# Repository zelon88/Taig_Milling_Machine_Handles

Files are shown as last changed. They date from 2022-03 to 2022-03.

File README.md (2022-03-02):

# Taig_Milling_Machine_Handles
In this repo you will find a set of axis control handles that can be attached to Taig milling machines to allow for manual operation of the machine. Replaces electronic stepper motors with analog handles. Allows the  operator of the machine to control the axis' by hand. 

Along with the original source code files in .scad format you will also find renderings of each component and detailed 3D printing, manufacturing & assembly instructions.

---

# Features
* Handles are optional and modular. Will function properly with any number of handles from 0-4.
* Set screws are located to maximize holding strength and material thickness around the hub.
* Handles are hollow for minimal mass and filament consumption, but still thick enough to survive being thrown around.
* Circular design is less likely to snag on clothing or interfere with nearby work.
* High quality design with real documentation.

# Component Description
* TMMH-001 is the center disk that all other components attach to.
* TMMH-002 is the handle that the operator uses to control the orientation of the center disk, and the axis of the machine.
* TMMH-003 is a washer that slides over the pin of the handle to reduce friction during rotation of the handle.
* TMMH-004 is a washer that secures a handle assembly to the center disk.
* TMMH-005 is an assembled model of one complete handle set. This model demonstrates what the final assembly should look like.
* TMMH-006 is a model that contains every component needed to build one complete handle set arranged for optimum printability.

# Notes
* For a 3 axis Taig CNC Milling Maching you will require 3 complete sets of handles.
* This handle design does not fit on the Taig 4th axis rotary table.
* If you like this design consider following & sponsoring me on Github, or other social media @zelon88.

# Pictures
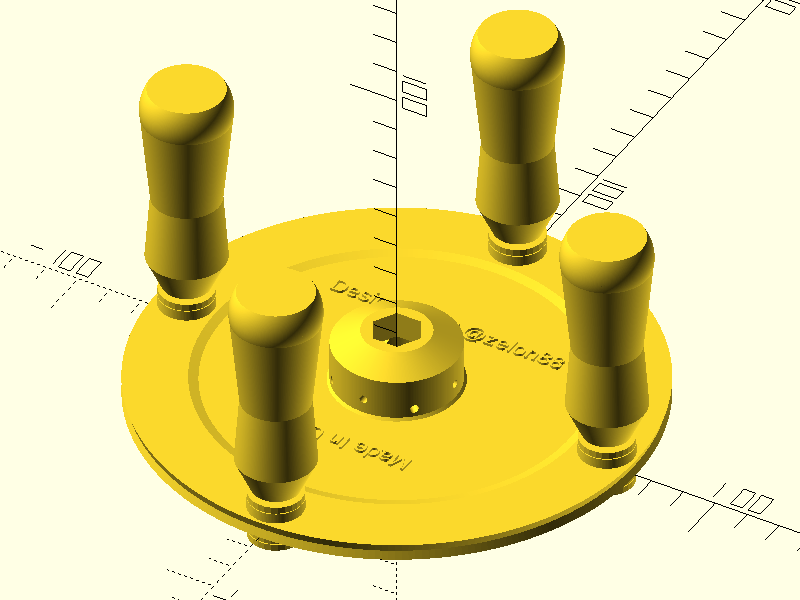
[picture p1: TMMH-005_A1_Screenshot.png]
Taig_Handles-5
	
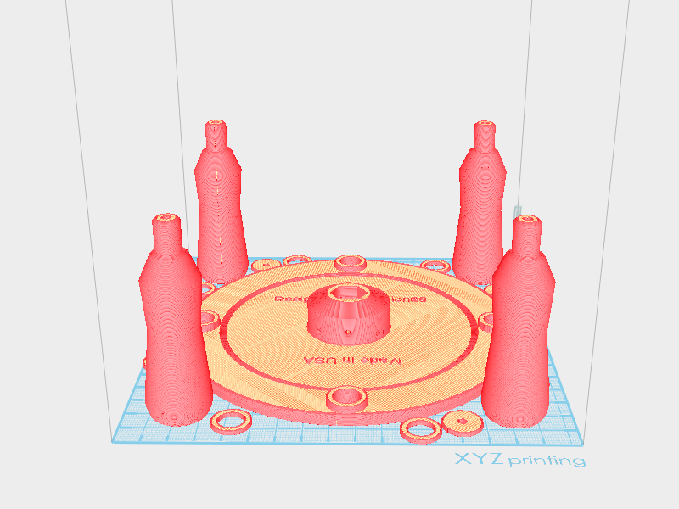
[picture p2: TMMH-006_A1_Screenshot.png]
Taig_Handles-6
	
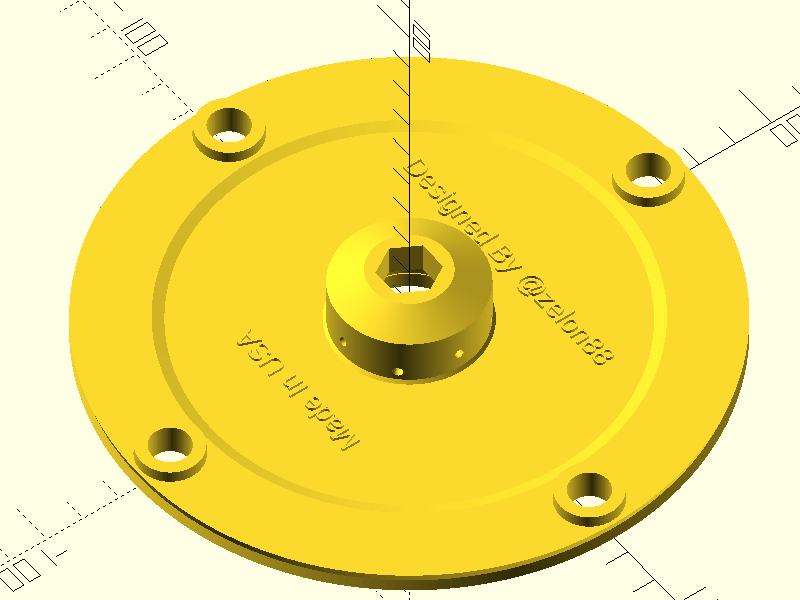
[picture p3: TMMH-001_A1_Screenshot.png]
Taig_Handles-1

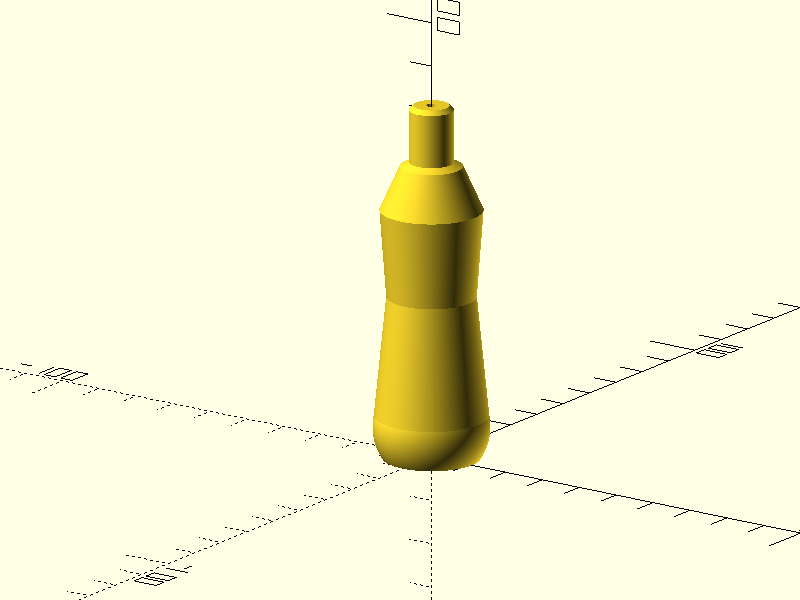
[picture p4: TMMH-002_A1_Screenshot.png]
Taig_Handles-2
	
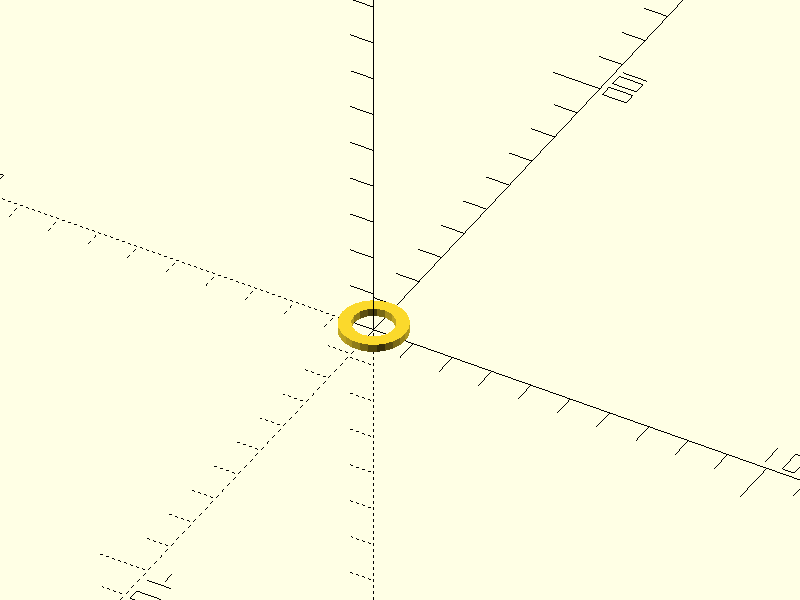
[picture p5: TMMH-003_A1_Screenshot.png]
Taig_Handles-3

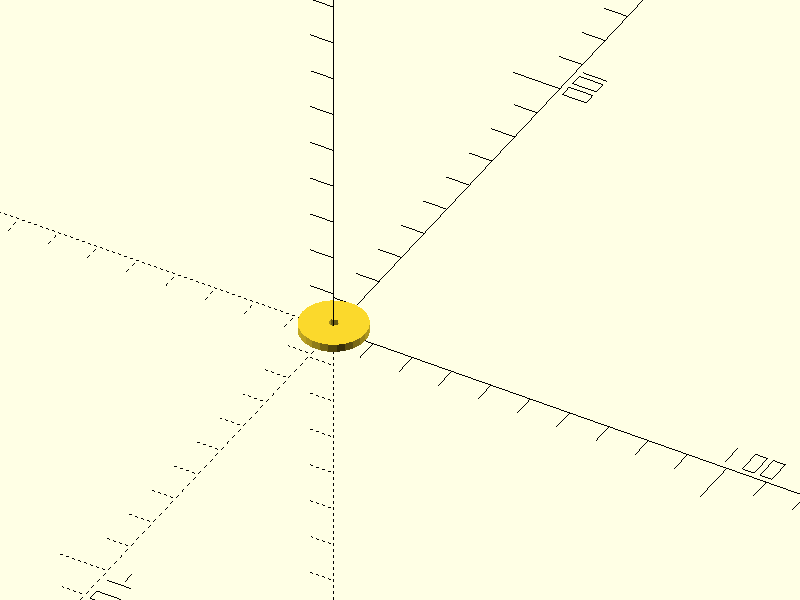
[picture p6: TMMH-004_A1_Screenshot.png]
Taig_Handles-4


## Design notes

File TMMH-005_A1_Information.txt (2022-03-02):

----------------------------------------------------------------------------------------------------
PROJECT INFORMATION

NAME:  Taig Milling Machine Handles
REVISION:  A1
START DATE:  2/28/2022
CURRENT VERSION DATE:  2/28/2022
LICENSE:  GPLv3
AUTHOR:  Justin Grimes (@zelon88)
DESCRIPTION:  A set of axis control handles that can be attached to Taig milling machines to allow for 
   manual operation of the machine. Replaces electronic stepper motors with analog handles. Allows the 
   operator of the machine to control the axis' by hand. 
----------------------------------------------------------------------------------------------------

----------------------------------------------------------------------------------------------------
PART INFORMATION

NAME:  Handle - Assembly
PART ID:  TMMH-005
REVISION:  A1
START DATE:  2/28/2022
CURRENT VERSION DATE:  2/28/2022
AUTHOR:  Justin Grimes (@zelon88)
DESCRIPTION:  The Handle Assembly contains all the components required to retrofit handles onto one 
   axis of a Taig Milling Machine. Three sets of handles are required to retrofit an entire 3 axis
   milling machine. In this assembly, four Modular Handles are shown attached to a central 
   Handle Wheel. The handle assembly function with any number of modular handles installed. 
FILE NAME: TMMH-005.scad
----------------------------------------------------------------------------------------------------

----------------------------------------------------------------------------------------------------
PRINTER CONFIGURATION

NOTE:  For bulk printing instructions; see "TMMH-006.scad".
NOTE:  For component printing instructions; see the ".scad" file for the desired component.
PRINTER TYPE:  XYZPrinting da Vinci Jr. 1.0A Pro
SLICER:  XYZPrint Version 2.0.21 
NOZZLE DIAMETER:  0.40mm
NOZZLE MATERIAL:  Copper
NOZZLE TEMPERATURE:  210c
NOZZLE FIRST LAYER TEMPERATURE:  215c
LAYER HEIGHT:  0.20mm
FIRST LAYER HEIGHT:  0.35mm
SHELL THICKNESS NORMAL:  2 Layers
SHELL THICKNESS TOP & BOTTOM SURFACE:  5 Layers
INNER SHELLS:  0mm
LIGHTWEIGHT:  No
INFILL DENSITY:  100%
INFILL TYPE:  Gyroid
DETAIL THRESHOLD:  0.001mm
AVOID CROSSING PRINTED PARTS:  No
SHELLS NORMAL SPEED:  30mm/s
SHELLS SURFACE SPEED:  30mm/s
SHELL SMALL RADIUS SPEED:  20mm/s
INFILL NORMAL SPEED:  45mm/s
INFILL TOP SURFACE SPEED:  45mm/s
SOLID INFILL SPEED:  45mm/s
BRIDGE PRINTING SPEED:  20mm/s
NON-PRINTING MOVEMENT SPEED:  50mm/s
BOTTOM LAYER SPEED:  10mm/s
RETRACT SPEED:  30mm/s
AUTO SPEED ADJUSTMENT FOR SMALL PARTS:  No
BRIM:  No
SUPPORTS:  No
RAFT:  No
RETRACT LENGTH:  4.5mm
ACTIVATE THRESHOLD (MIN TRAVEL LENGTH):  2mm
RETRACTION NOZZLE LIFT:  0mm
ADD EXTRA FILAMENT (WHEN TRAVEL < RETRACTION):  0mm
RETRACT EACH LAYER:  Yes
DISABLE RETRACTION CURRENT PERIMETER:  Yes
SHELL EXTRUSION RATIO:  100%
SHELL FILL EXTRUSION RATIO:  100%
INFILL EXTRUSION RATIO:  100%
SEAM CORNER PREFERENCES:  "Smart Hiding"
----------------------------------------------------------------------------------------------------

----------------------------------------------------------------------------------------------------
PARTS LIST

1x Handle - Wheel, TMMH-001 
4x Handle - Modular Handle, TMMH-002 
8x Handle - Modular Washer, TMMH-003 
4x Handle - Modular Endcap, TMMH-004 
8x Screws, M2.5 x 8mm 
4x Screws, M2.5 x 10mm 
12x Drops Threadlocker, Loctite Blue or Red
----------------------------------------------------------------------------------------------------

----------------------------------------------------------------------------------------------------
MANUFACTURING INSTRUCTIONS

1. Remove the desired servo motor from the Taig Milling Machine.
2. Slide TMMH-001 onto the exposed axis hub of the Taig Milling Machine with the flat side of the 
 TMMH-001 facing towards the milling machine.
3. Insert 8x M2.5 x 8mm screws into the 8x small holes located around the center hub of TMMH-001.
4. Insert TMMH-003 onto the small end of TMMH-002.
5. Insert TMMH-002 into one of the 4 large holes in TMMH-001 so that TMMH-002 is pointed away from 
 the milling machine.
6, Slowly complete one rotation of the newly installed axis before completing any more 
 installation steps. Ensure that the handle can rotate freely and is free from any obstructions.
7. Insert TMMH-003 onto the small end of TMMH-001 that remains exposed through TMMH-001.
8. Insert an M2.5 x 10mm screw into the small hole of TMMH-004 and apply one drop of 
 threadlocker to the threads.
9. Thread the M2.5 x 10mm screw with TMMH-004 attached into the small hole at the end of TMMH-002. 
10. Repeat steps 4 through 9 to add as many handles as desired.
11. Repeat steps 1 through 10 to replace as many servos as desired.
----------------------------------------------------------------------------------------------------

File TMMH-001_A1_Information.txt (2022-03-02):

----------------------------------------------------------------------------------------------------
PROJECT INFORMATION

NAME:  Taig Milling Machine Handles
REVISION:  A1
START DATE:  2/28/2022
CURRENT VERSION DATE:  2/28/2022
LICENSE:  GPLv3
AUTHOR:  Justin Grimes (@zelon88)
DESCRIPTION:  A set of axis control handles that can be attached to Taig milling machines to allow for 
   manual operation of the machine. Replaces electronic stepper motors with analog handles. Allows the 
   operator of the machine to control the axis' by hand. 
----------------------------------------------------------------------------------------------------

----------------------------------------------------------------------------------------------------
PART INFORMATION

NAME:  Handle - Wheel
PART ID:  TMMH-001
REVISION:  A1
START DATE:  2/28/2022
CURRENT VERSION DATE:  2/28/2022
AUTHOR:  Justin Grimes (@zelon88)
DESCRIPTION:  The Handle Wheel serves as the body of the handle that attaches to the machine.
   All other components of this assembly are built to attach to this piece. This file defines a 
   module named "handleWheel()" which can be called with no arguments to render the handle. 
   This file is included in "TMMH-005.scad" which is an assembled model of the project, and 
   in "TMMH-006.scad" which has all components arranged for 3D Printing.
FILE NAME: TMMH-001.scad
----------------------------------------------------------------------------------------------------

----------------------------------------------------------------------------------------------------
PRINTER CONFIGURATION

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

----------------------------------------------------------------------------------------------------
PARTS LIST

1. 20m PLA Filament
----------------------------------------------------------------------------------------------------

----------------------------------------------------------------------------------------------------
MANUFACTURING INSTRUCTIONS

1. Visually inspect for damage or manufacturing irregularities.
2. File to remove any burrs or rough edges.
3. DO NOT chase any holes with a drill bit.
4. Verify overall thickness of the 4x gussets of 8mm +/- 5% with micrometers (preferred) or calipers. 
 Do not measure with a drop-height indicator.
5. Verify the diameter of the 4x gusset holes of 10mm +/- 5% with a gage pin (preferred) or calipers.
6. Verify the flatness of +/- 5mm across the bottom (flat) side with a surface plate & feeler gages.
7. Minor curling around bottom edge is acceptable if installed handles are perpendicular +/- 1 degree.
----------------------------------------------------------------------------------------------------

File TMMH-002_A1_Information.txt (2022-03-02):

----------------------------------------------------------------------------------------------------
PROJECT INFORMATION

NAME:  Taig Milling Machine Handles
REVISION:  A1
START DATE:  2/28/2022
CURRENT VERSION DATE:  2/28/2022
LICENSE:  GPLv3
AUTHOR:  Justin Grimes (@zelon88)
DESCRIPTION:  A set of axis control handles that can be attached to Taig milling machines to allow for 
   manual operation of the machine. Replaces electronic stepper motors with analog handles. Allows the 
   operator of the machine to control the axis' by hand. 
----------------------------------------------------------------------------------------------------

----------------------------------------------------------------------------------------------------
PART INFORMATION

NAME:  Handle - Modular Handle
PART ID:  TMMH-002
REVISION:  A1
START DATE:  2/28/2022
CURRENT VERSION DATE:  2/28/2022
AUTHOR:  Justin Grimes (@zelon88)
DESCRIPTION:   The Modular Handle Insert serves as a comfortable & ergonomic handle that fits in the 
   operators hand. This piece applies torque from the operator to the Handle Wheel (TMMH-001) which 
   controls one axis of the attached machine. This file defines a module named "modularHandle()" which 
   can be called with no arguments to render the handle. This file is included in "TMMH-005.scad" which
   is an assembled model of the project, and in "TMMH-006.scad" which has all components arranged for 
   3D Printing.
FILE NAME: TMMH-002.scad
----------------------------------------------------------------------------------------------------

----------------------------------------------------------------------------------------------------
PRINTER CONFIGURATION

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

1. 10m PLA Filament
----------------------------------------------------------------------------------------------------

----------------------------------------------------------------------------------------------------
MANUFACTURING INSTRUCTIONS

1. Visually inspect for damage or manufacturing irregularities.
2. File to remove any burrs or rough edges.
3. DO NOT chase any holes with a drill bit. A snug fit for M2.5 screws is required.
4. Verify diameter of small pin section of 10mm +/- 5% with calipers.
5. Verify overall length of small pin section of 12mm +10%, -2% with calipers.
----------------------------------------------------------------------------------------------------

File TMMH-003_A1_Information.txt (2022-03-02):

----------------------------------------------------------------------------------------------------
PROJECT INFORMATION

NAME:  Taig Milling Machine Handles
REVISION:  A1
START DATE:  2/28/2022
CURRENT VERSION DATE:  2/28/2022
LICENSE:  GPLv3
AUTHOR:  Justin Grimes (@zelon88)
DESCRIPTION:  A set of axis control handles that can be attached to Taig milling machines to allow for 
   manual operation of the machine. Replaces electronic stepper motors with analog handles. Allows the 
   operator of the machine to control the axis' by hand. 
----------------------------------------------------------------------------------------------------

----------------------------------------------------------------------------------------------------
PART INFORMATION

NAME:  Handle - Modular Washer
PART ID:  TMMH-003
REVISION:  A1
START DATE:  2/28/2022
CURRENT VERSION DATE:  2/28/2022
AUTHOR:  Justin Grimes (@zelon88)
DESCRIPTION:   The Modular washer serves to spread the load of the modular handles to the support 
   gussets built into the handle wheel. They also act as a friction surface between the handle wheel & 
   modular handles. This file defines a module named "modularWasher()" which can be called with no 
   arguments to render the handle. This file is included in "TMMH-005.scad" which is an assembled model 
   of the project, and in "TMMH-006.scad" which has all components arranged for 3D Printing.
FILE NAME: TMMH-003.scad
----------------------------------------------------------------------------------------------------

----------------------------------------------------------------------------------------------------
PRINTER CONFIGURATION

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

----------------------------------------------------------------------------------------------------
PARTS LIST

1. 0.1m PLA Filament
----------------------------------------------------------------------------------------------------

----------------------------------------------------------------------------------------------------
MANUFACTURING INSTRUCTIONS

1. Visually inspect for damage or manufacturing irregularities.
2. File to remove any burrs or rough edges.
3. DO NOT chase any holes with a drill bit.
4. Verify overall thickness of 2mm +/- 5% with calipers (preferred) or a drop-height indicator.
----------------------------------------------------------------------------------------------------

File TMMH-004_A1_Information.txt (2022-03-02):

----------------------------------------------------------------------------------------------------
PROJECT INFORMATION

NAME:  Taig Milling Machine Handles
REVISION:  A1
START DATE:  2/28/2022
CURRENT VERSION DATE:  2/28/2022
LICENSE:  GPLv3
AUTHOR:  Justin Grimes (@zelon88)
DESCRIPTION:  A set of axis control handles that can be attached to Taig milling machines to allow for 
   manual operation of the machine. Replaces electronic stepper motors with analog handles. Allows the 
   operator of the machine to control the axis' by hand. 
----------------------------------------------------------------------------------------------------

----------------------------------------------------------------------------------------------------
PART INFORMATION

NAME:  Handle - Modular Endcap
PART ID:  TMMH-004
REVISION:  A1
START DATE:  2/28/2022
CURRENT VERSION DATE:  2/28/2022
AUTHOR:  Justin Grimes (@zelon88)
DESCRIPTION:   The Modular Endcap serves to spread the load of the modular handles to the support 
   gussets built into the handle wheel. They also act as a friction surface between the modular 
   handles &  modular washers. This file defines a module named "modularEndcap()" which can be called 
   with no arguments to render the endcap. This file is included in "TMMH-005.scad" which is an 
   assembled model of the project, and in "TMMH-006.scad" which has all components arranged for 
   3D Printing.
FILE NAME: TMMH-004.scad
----------------------------------------------------------------------------------------------------

----------------------------------------------------------------------------------------------------
PRINTER CONFIGURATION

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

----------------------------------------------------------------------------------------------------
PARTS LIST

1. 0.2m PLA Filament
----------------------------------------------------------------------------------------------------

----------------------------------------------------------------------------------------------------
MANUFACTURING INSTRUCTIONS

1. Visually inspect for damage or manufacturing irregularities.
2. File to remove any burrs or rough edges.
3. DO NOT chase any holes with a drill bit. A snug fit for M2.5 screws is required.
4. Verify overall thickness of 2mm +/- 5% with calipers (preferred) or a drop-height indicator.
----------------------------------------------------------------------------------------------------

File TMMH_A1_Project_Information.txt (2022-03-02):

----------------------------------------------------------------------------------------------------
PROJECT INFORMATION

NAME:  Taig Milling Machine Handles
REVISION:  A1
START DATE:  2/28/2022
CURRENT VERSION DATE:  2/28/2022
LICENSE:  GPLv3
AUTHOR:  Justin Grimes (@zelon88)
DESCRIPTION:  A set of axis control handles that can be attached to Taig milling machines to allow for 
   manual operation of the machine. Replaces electronic stepper motors with analog handles. Allows the 
   operator of the machine to control the axis' by hand. 
----------------------------------------------------------------------------------------------------

----------------------------------------------------------------------------------------------------
PARTS LIST

1x Handle - Wheel, TMMH-001 
  20m PLA Filament Each (20m Total)

4x Handle - Modular Handle, TMMH-002 
  10m PLA Filament Each (40m Total)

8x Handle - Modular Washer, TMMH-003 
  0.1m PLA Filament Each (0.8m Total)

4x Handle - Modular Endcap, TMMH-004 
  0.2m PLA Filament Each (0.8m Total)

8x Screws, M2.5 x 8mm 

4x Screws, M2.5 x 10mm 

12x Drops Threadlocker, Loctite Blue or Red
----------------------------------------------------------------------------------------------------

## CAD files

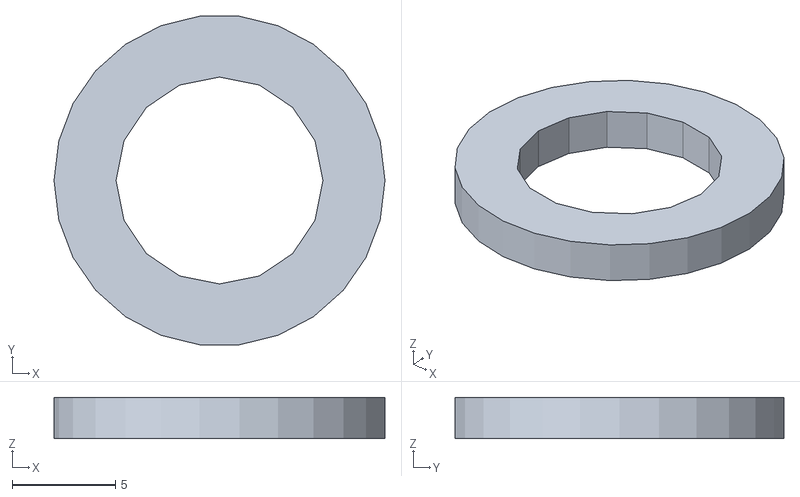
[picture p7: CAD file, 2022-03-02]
TMMH-003_A1.stl
16.0 x 15.9 x 2.00

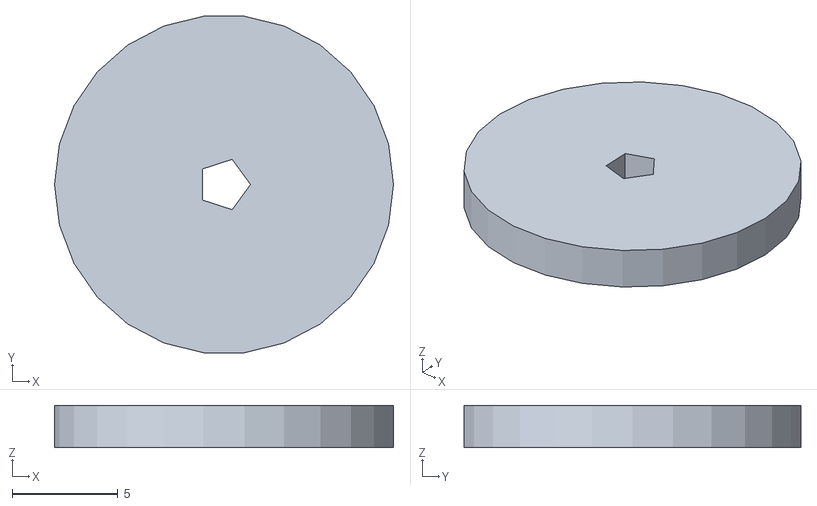
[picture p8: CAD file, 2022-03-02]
TMMH-004_A1.stl
16.0 x 15.9 x 2.00

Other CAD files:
TMMH-001.scad
TMMH-002.scad
TMMH-003.scad
TMMH-004.scad
TMMH-005.scad

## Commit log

2022-03-02 Upload files to Github.
    I made these handles for a Taig 3 axis milling machine so it can be operated manually, without electronics.
    [TMMH-001.scad, TMMH-002.scad, TMMH-003.scad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]
2022-03-02 Fix typo.
    DIAMETERDiameter changed to DIAMETER as it should be.
    [TMMH-001.scad, TMMH-002.scad, TMMH-003.scad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]
2022-03-02 More typos.
    Sadly, "completiting" isn't a word. Changed to "completing".
    [TMMH-005.scad]
